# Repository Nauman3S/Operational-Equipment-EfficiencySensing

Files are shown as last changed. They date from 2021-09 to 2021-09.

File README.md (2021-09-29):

<p align="center">
  <a href="" rel="noopener">
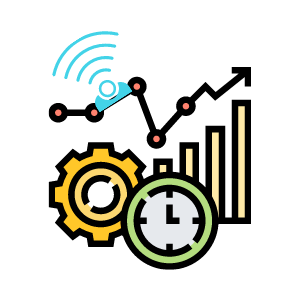
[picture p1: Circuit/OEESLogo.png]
Project logo
 </a>
</p>

<h3 align="center">Operational Equipment Efficieny Sensing</h3>

<div align="center">

[]()

</div>

---

<p align="center"> Operational Equipment Efficieny Sensing
    <br> 
</p>

## 📝 Table of Contents

- [About](#about)
- [Getting Started](#getting_started)
- [RPiClient Installation](#Installation)
- [Circuit](#circuit)
- [Usage](#usage)
- [Built Using](#built_using)
- [Authors](#authors)

## 🧐 About 

This repo contains

- Firmware
- Circuit Diagram
- Detailed instructions

for OEESensing project.

## Getting Started 

These instructions will get you a copy of the project up and running on your system.

### Prerequisites

Things you need to install the FW.

```
- Arduino IDE
```

### Installing 

A step by step series that tell you how to get the Firmware and Backend running

#### ESP32 Configuration

You should have Arduino IDE Installed

  1.  Add ESP32 Board to your Arduino IDE
    1. In your Arduino IDE, go to File> Preferences
        Installing ESP32 Add-on in Arduino IDE Windows, Mac OS X, Linux open preferences
    2. Enter ```https://dl.espressif.com/dl/package_esp32_index.json``` 
        into the “Additional Board Manager URLs” field then, click the “OK” button:
        Note: if you already have the ESP32 boards URL, you can separate the URLs with a comma(each board will go to neaw line) as follows:
        ```https://dl.espressif.com/dl/package_esp32_index.json,\n http://arduino.esp8266.com/stable/package_esp8266com_index.json```

  2. Open the Boards Manager. Go to Tools > Board > Boards Manager…
  3. Search for ESP32 and press install button for the ESP32 by Espressif Systems“:
  4. That’s it. It should be installed after a few seconds.
  5.   In your Arduino sketchbook directory, create tools directory if it doesn't exist yet.
  6.  Unpack the tool into tools directory(present in libs/ESP32FS-1.0.zip) (the path will look like <home_dir>/Arduino/tools/ESP32FS/tool/esp32fs.jar).
  7.  Close and re-open the Arduino IDE.

  8.  Now copy the contents of the libs folder to the libraries directory of your Arduino
      1. If you are using windows, the libraries directory will be Documents/Arduino/libraries

##### ESP32 Node FW Uploading
  1.  Select ESP32 Dev Module from Tools->Board->ESP32
  2.  Select the correct port from Tools->Port
  3.  Then open Firmware.ino file,
  4.  Select Tools > ESP32 Sketch Data Upload menu item. This should start uploading the files into ESP32 flash file system.
  5.  Now Upload the Code to your ESP32 Dev Module.
  6.  Your ESP32 is now ready to be used.

## Circuit 

### ESP32 Dev Module Pinout

Follow the pinout diagram given below to connect different components to your TTGO LORA32 board.

![LoraPinout](Circuit/ESP32-Pinout.jpg)

### Other Components

```http
Other components pin connection details
```

#### Temperature Sensor DHT22

```DHT22 Connections```

| DHT22 Pins | ESP32 Dev Module Pins| 
| :--- | :--- | 
| `DATA OUT` | `23` |
| `VCC` | `5V` |
| `GND` | `GND` | 

#### Vibration Sensor(MPU6050)

```MPU6050 Connections```

| MPU6050 Pins | ESP32 Dev Module | 
| :--- | :--- | 
| `SCL` | `22` |
| `SDA` | `21` |
| `VCC` | `3.3V` |
| `GND` | `GND` | 

#### Status LED

```LED Connections```

| LED Pins | ESP32 Dev Module | 
| :--- | :--- | 
| `Anode` | `D2 via 220Ω resistor` |
| `Cathode` | `GND` |
*D2 is also connected to the internal LED of ESP32 Dev Module*

#### SCT-013 

```SCT-013 Connections```

-   Voltage Divider with 2x 100KΩ resistors.
-   10uF capacitor connected between Voltage Divider Circuit Output and GND
-   3.5mm Audio Jack connected between Voltage Divider Circuit Output and ESP32 Pin 34.

The overall SCT-013 connection assembly will look something like shown in the diagram below.

![SCTConnection](Circuit/sctWiring.jpg)

### Complete Circuit Diagram

Here's the complete circuit diagram of the system.

![CircuitDiagram](Circuit/Circuit_bb.png)

## Usage 

1.  Power on your ESP32, it will present you with an AP named ```OEE``` (while ```OEE``` can be changed in the portal)
2.  Default captive portal password `12345678AP` which can be changed in captive portal.
3.  Connect to the ESP32 access point and open the web-browser and navigate to the link ```http://esp32.local/_ac```. This link will work on most of the operating systems but if your operating system is not allowing to open it, you may want to check the captive portal IP Address from the serial monitor and can use that IP address inplace of the above mentioned URL.
4.  The default access IP Address is ```http://192.168.4.1/_ac```
5.  You will be presented with a main dashboard as shown below(based on your device)
   ![SCR1](Circuit/scr1.png)

5.  Once connected to a WiFi network, you can again access the captive portal using same URL or the IP Address from the Serial monitor.
6.  The data is published to the MQTT Topic ```OEE/{hostname}``` while the hostname is the one which you can define in Settings page of the captive portal.

The whole system is following the flowchart given below:

   ![flow](Circuit/flow.png)

### Changing Timezone

1.  Open Settings tab
2.  Enter timezone string from https://en.wikipedia.org/wiki/List_of_tz_database_time_zones 'TZ database name' column.
3.  Click Save&Start

### API Endpoints and HTML URLS
```API Endpoints```

| Endpoint | Description | 
| :--- | :--- | 
| `/api-now` | `API: live sensor readings in JSON format` |
| `/api` | `API: historical sensors data in JSON format` |
| `/LiveSensors` | `HTML PAGE: Live Sensor Data` |
| `/data` | `HTML PAGE: Historical Sensor Data` | 
| `/mqtt_settings` | `HTML PAGE: Settings. Default username: AP Name, Default Password: admin` | 
| `/_ac` | `HTML PAGE: Main Captive portal page` | 
| `/` | `HTML PAGE: Historical Sensor Data` | 

1.  **Connect to WiFi** tab allows searching of nearby WiFi APs and adding them to the ESP32.
   ![SCR3](Circuit/scr3.png)
7.  **Saved WiFi Networks** tab allows connecting to the saved access points.
   ![SCR4](Circuit/scr4.png)
8.  **Reset...** tab allows reseting of the device to factory settings.
    ![SCR5](Circuit/scr5.png)
9.  **Settings** tab contains settings related to MQTT and sensors.
    ![SCR6](Circuit/scr6.png)
10. **api-now** tab gives the live-sensor data in JSON format.
    ![SCR7](Circuit/scr7.png)
11. **api** tab gives the historical sensor data acquired after every 5 mintues.
    ![SCR9](Circuit/scr9.png)
13. **LiveSensors** tab shows live values of the sensors.
    ![SCR8](Circuit/scr8.png)
12. **HOME** tab shows historical sensor data in a HTML table form acquired after every 5 minutes.
    ![SCR10](Circuit/scr10.png)

## List of Components 

Following components are used to make this project

1.  ESP32 Dev Kit Module
https://www.amazon.com/HiLetgo-ESP-WROOM-32-Development-Microcontroller-Integrated/dp/B0718T232Z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

2.  Current Sensor (SCT-013)
https://www.amazon.com/dp/B083S6YG36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

3.  DHT22 Temperature and Humidity Sensor
https://www.amazon.com/Gowoops-Temperature-Humidity-Measurement-Raspberry/dp/B073F472JL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

4.  Vibration Sensor (IMU) (MPU6050)
https://www.amazon.com/HiLetgo-MPU-6050-Accelerometer-Gyroscope-Converter/dp/B00LP25V1A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

5.  Generic 3.5mm Green LED
6.  Generic 3.5mm Audio Jack
7.  Generic 10uF 25v Capacitor
8.  Generic 220Ω and 100KΩ resistors
9.  Generic 5V USB Micro B cable and adapter.

## ⛏️ Built Using 

- [Python](https://www.python.org/) - For Cloud Gateway Pogramming
- [Arduino](https://www.arduino.cc/) - Embedded Framework and IDE - For Sensor Node Design

## 📹 Demo Videos 

-   [Device Demo Video](https://youtu.be/YtVo1j4n8tg) - OEE Device Demo Video

## ✍️ Authors 

- [@Nauman3S](https://github.com/Nauman3S) - Development and Deployment

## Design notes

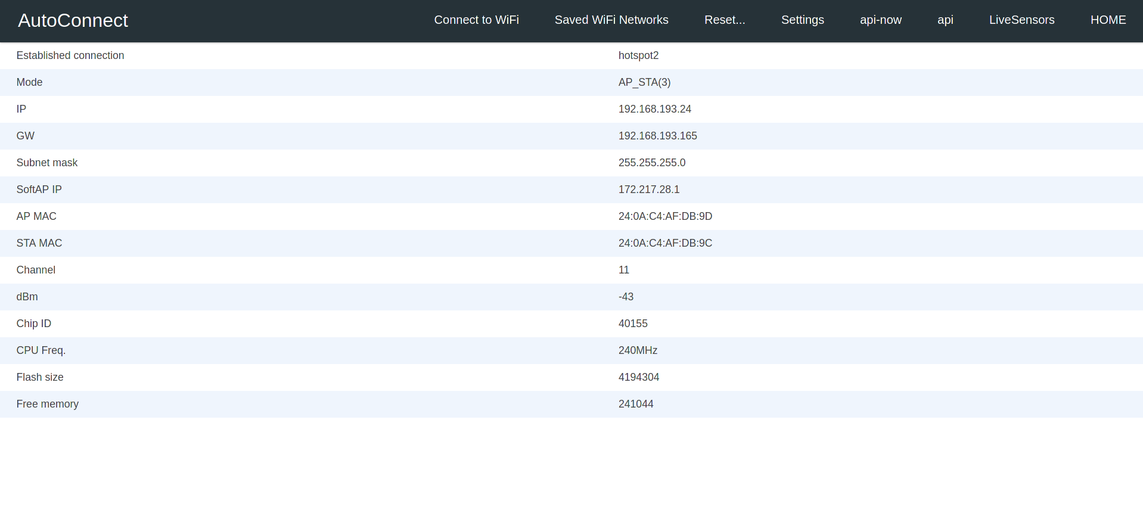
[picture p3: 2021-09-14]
Circuit/scr1.png

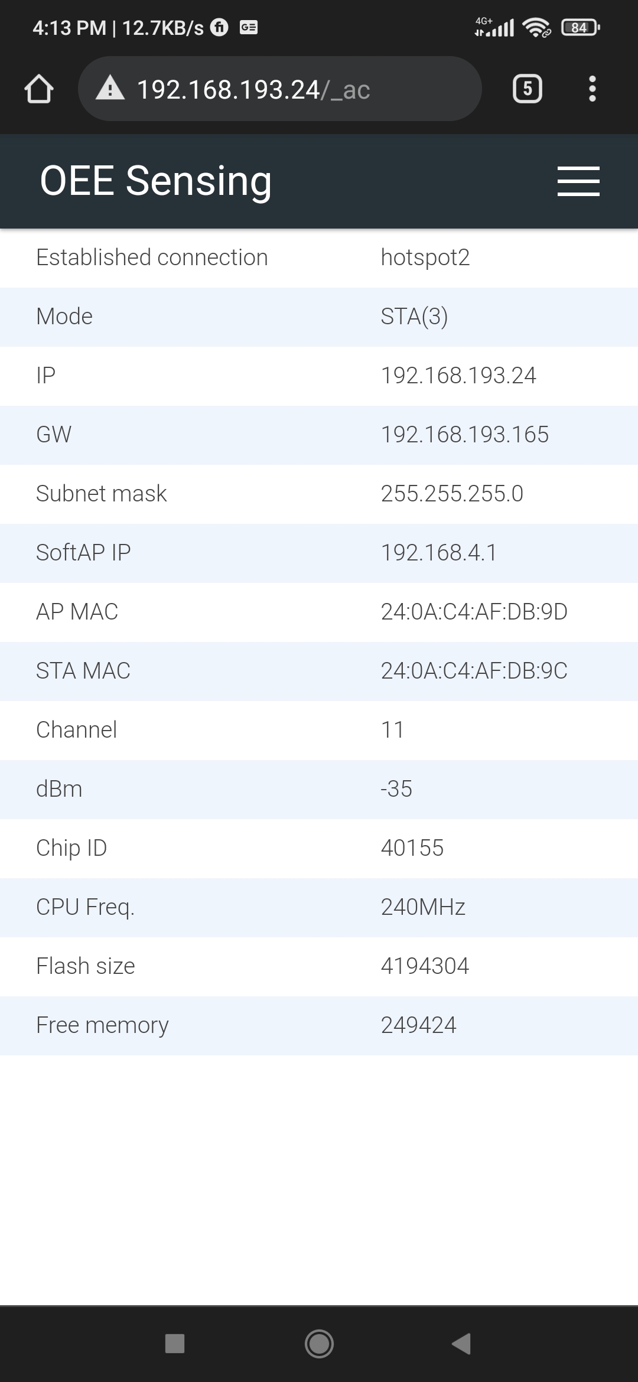
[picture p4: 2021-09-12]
Circuit/scr2.jpg

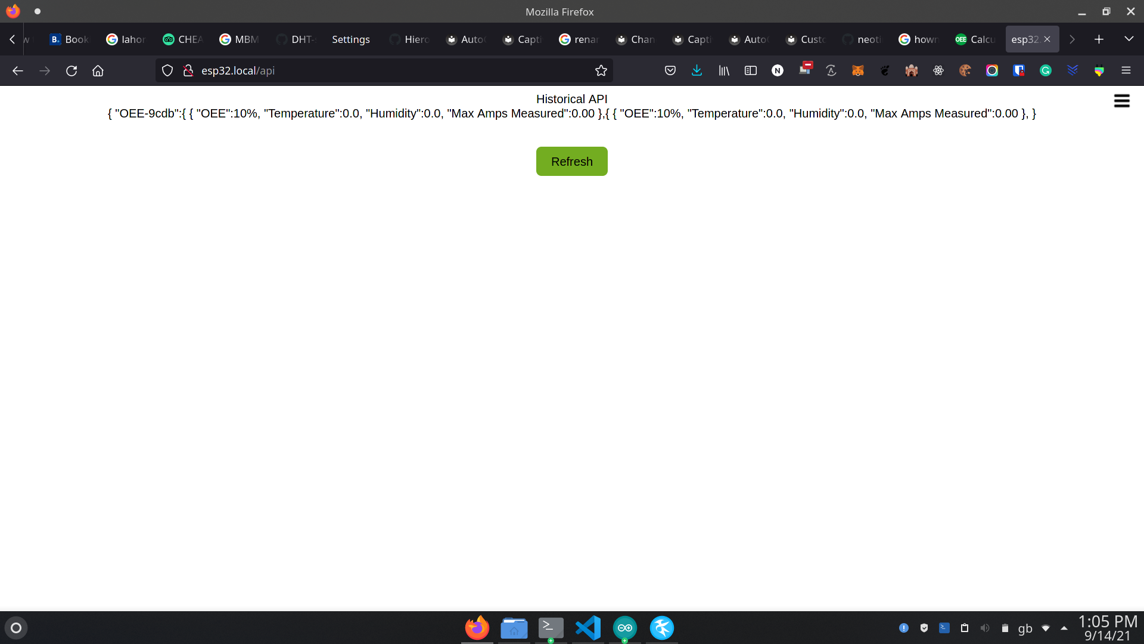
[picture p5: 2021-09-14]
Circuit/scr9.png

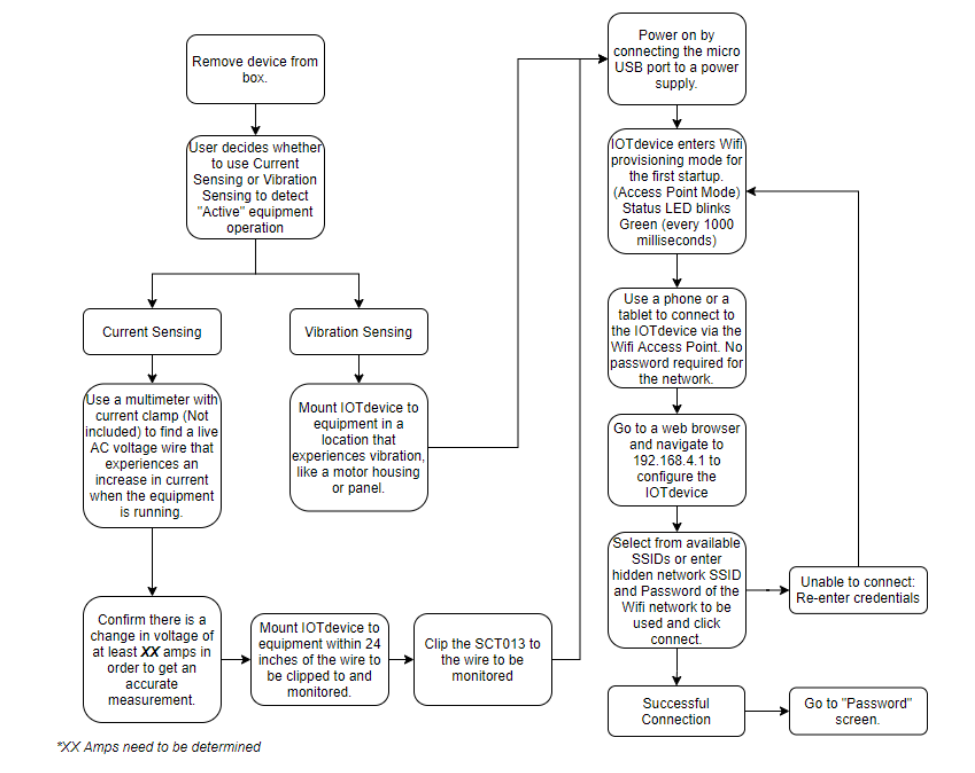
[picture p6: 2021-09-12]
Circuit/flow.png

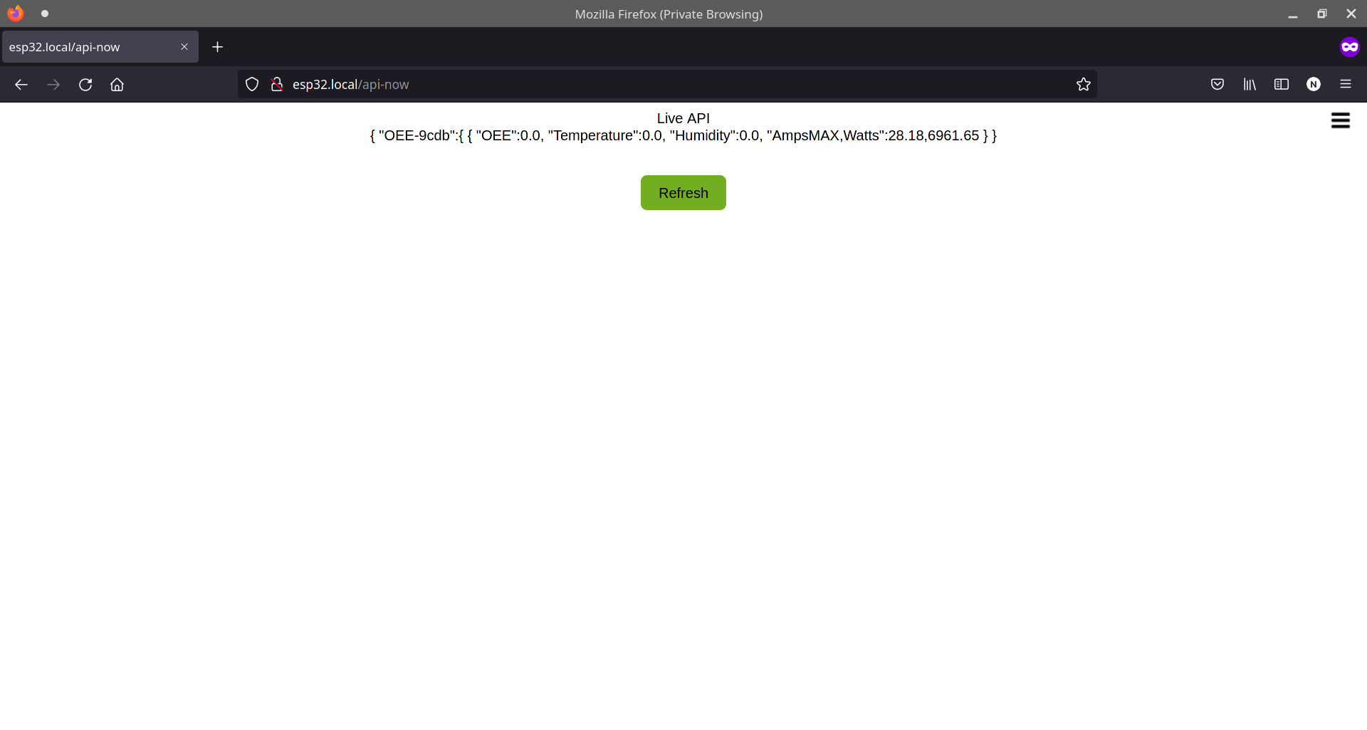
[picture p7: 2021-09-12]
Circuit/scr7.png

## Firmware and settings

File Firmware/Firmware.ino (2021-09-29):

#include "dhtHandler.h"           //temperature and humidity functions
#include "mpu6050Handler.h"       //IMU MPU6050 functions
#include "currentSesnorHandler.h" //current sensor functions
#include "headers.h"              //all misc. headers and functions
#include "esp32InternalTime.h"
#include "MQTTFuncs.h" //MQTT related functions
#include "webApp.h"    //Captive Portal webpages
#include <FS.h>        //ESP32 File System

const long interval = 1000 * 60 * 5;        // Interval at which to read sensors//5 mintues
Neotimer dataAcqTimer = Neotimer(interval); // Set timer's preset
Neotimer sensorsDataTimer = Neotimer(1000); // Set timer's preset

IPAddress ipV(192, 168, 4, 1);
String loadParams(AutoConnectAux &aux, PageArgument &args) //function to load saved settings
{
    (void)(args);
    File param = FlashFS.open(PARAM_FILE, "r");
    String v1 = "";
    String v2 = "";
    if (param)
    {
        Serial.println("load params func");
        aux.loadElement(param);
        Serial.println(param);
        //Serial.println(args);
        AutoConnectText &vibSValueElm = aux["vibSValue"].as<AutoConnectText>();
        AutoConnectText &curSValueElm = aux["curSValue"].as<AutoConnectText>();
        //vibSValueElm.value="VibS:91122";#
        Serial.println(vibSValueElm.value);
        v1 = String(vibSValueElm.value);
        v2 = String(curSValueElm.value);
        if (v1.length() > 0)
        {
            vibSValueElm.value = String("Vibration: ") + getMPU6050Data();
        }
        if (v2.length() > 0)
        {
            curSValueElm.value = String("Current: ") + getCurrentWatts();
        }
        // curSValueElm.value="CurS:7788";
        param.close();
    }
    else
        Serial.println(PARAM_FILE " open failed");
    return String("");
}

String saveParams(AutoConnectAux &aux, PageArgument &args) //save the settings
{
    serverName = args.arg("mqttserver"); //broker
    serverName.trim();

    channelId = args.arg("channelid");
    channelId.trim();

    userKey = args.arg("userkey"); //user name
    userKey.trim();

    apiKey = args.arg("apikey"); //password
    apiKey.trim();

    timezone = args.arg("timezone"); //timezone
    timezone.trim();

    minActiveValue = args.arg("minActiveValue");
    minActiveValue.trim();

    ampSensorType = args.arg("ampSensorType");
    ampSensorType.trim();
    ampSensorType = ampSensorType.substring(0, 2);

    tempUnits = args.arg("tempUnits");
    tempUnits.trim();

    String upd = args.arg("period");
    upd = upd.substring(0, 2);
    sensorSelection = upd;

    apPass = args.arg("apPass"); //ap pass
    apPass.trim();

    settingsPass = args.arg("settingsPass"); //ap pass
    settingsPass.trim();

    hostName = args.arg("hostname");
    hostName.trim();

    // The entered value is owned by AutoConnectAux of /mqtt_setting.
    // To retrieve the elements of /mqtt_setting, it is necessary to get
    // the AutoConnectAux object of /mqtt_setting.
    File param = FlashFS.open(PARAM_FILE, "w");
    portal.aux("/mqtt_setting")->saveElement(param, {"mqttserver", "channelid", "userkey", "apikey", "timezone", "period", "minActiveValue", "ampSensorType", "tempUnits", "hostname", "apPass", "settingsPass"});
    param.close();

    // Echo back saved parameters to AutoConnectAux page.
    AutoConnectText &echo = aux["parameters"].as<AutoConnectText>();
    echo.value = "Server: " + serverName + "<br>";
    echo.value += "Channel ID: " + channelId + "<br>";
    echo.value += "Timezone: " + timezone + "<br>";
    echo.value += "Username: " + userKey + "<br>";
    echo.value += "Password: " + apiKey + "<br>";
    echo.value += "Sensor Settings: " + String(upd) + "<br>";
    echo.value += "Min Active Value: " + minActiveValue + "<br>";
    echo.value += "Amp Sensor Type: " + ampSensorType + "<br>";
    echo.value += "Temperature Units: " + tempUnits + "<br>";
    echo.value += "ESP host name: " + hostName + "<br>";
    echo.value += "AP Password: " + apPass + "<br>";
    echo.value += "Settings Page Password: " + settingsPass + "<br>";
    mqttPublish("OEEDevice/dev/config", String("tz;") + timezone); //publish timezone info
    return String("");
}
bool loadAux(const String auxName) //load defaults from data/*.json
{
    bool rc = false;
    Serial.println("load aux func");
    String fn = auxName + ".json";
    File fs = FlashFS.open(fn.c_str(), "r");
    if (fs)
    {
        rc = portal.load(fs);
        fs.close();
    }
    else
        Serial.println("Filesystem open failed: " + fn);
    return rc;
}
uint8_t inAP = 0;
bool whileCP()
{

    if (inAP == 0)
    {
        ledState(AP_MODE);
        inAP = 1;
    }
    // Serial.println("AP MODE");

    loopLEDHandler();
}

void setup() //main setup functions
{
    Serial.begin(115200);
    delay(1000);
    setupDHT22();
    setupMPU6050();
    setupCurrentSensor();

    if (!MDNS.begin("esp32")) //starting mdns so that user can access webpage using url `esp32.local`(will not work on all devices)
    {
        Serial.println("Error setting up MDNS responder!");
        while (1)
        {
            delay(1000);
        }
    }
#if defined(ARDUINO_ARCH_ESP8266)
    FlashFS.begin();
#elif defined(ARDUINO_ARCH_ESP32)
    FlashFS.begin(true);
#endif
    loadAux(AUX_MQTTSETTING);
    loadAux(AUX_MQTTSAVE);
    AutoConnectAux *setting = portal.aux(AUX_MQTTSETTING);
    if (setting) //get all the settings parameters from setting page on esp32 boot
    {
        Serial.println("Setting loaded");
        PageArgument args;
        AutoConnectAux &mqtt_setting = *setting;
        loadParams(mqtt_setting, args);
        AutoConnectInput &hostnameElm = mqtt_setting["hostname"].as<AutoConnectInput>();
        AutoConnectInput &apPassElm = mqtt_setting["apPass"].as<AutoConnectInput>();
        AutoConnectInput &serverNameElm = mqtt_setting["mqttserver"].as<AutoConnectInput>();
        AutoConnectInput &channelidElm = mqtt_setting["channelid"].as<AutoConnectInput>();
        AutoConnectInput &userkeyElm = mqtt_setting["userkey"].as<AutoConnectInput>();
        AutoConnectInput &apikeyElm = mqtt_setting["apikey"].as<AutoConnectInput>();
        AutoConnectInput &minActiveValueElm = mqtt_setting["minActiveValue"].as<AutoConnectInput>();
        AutoConnectRadio &ampSensorTypeElm = mqtt_setting["ampSensorType"].as<AutoConnectRadio>();
        AutoConnectRadio &tempUnitsElm = mqtt_setting["tempUnits"].as<AutoConnectRadio>();
        AutoConnectRadio &periodElm = mqtt_setting["period"].as<AutoConnectRadio>();
        AutoConnectText &vibSValueElm = mqtt_setting["vibSValue"].as<AutoConnectText>();
        AutoConnectText &curSValueElm = mqtt_setting["curSValue"].as<AutoConnectText>();
        AutoConnectInput &settingsPassElm = mqtt_setting["settingsPass"].as<AutoConnectInput>();
        //vibSValueElm.value="VibS:11";
        serverName = String(serverNameElm.value);
        channelId = String(channelidElm.value);
        userKey = String(userkeyElm.value);
        apiKey = String(apikeyElm.value);
        minActiveValue = String(minActiveValueElm.value);
        ampSensorType = String(ampSensorTypeElm.value());
        tempUnits = String(tempUnitsElm.value());
        sensorSelection = String(periodElm.value());
        hostName = String(hostnameElm.value);
        apPass = String(apPassElm.value);
        settingsPass = String(settingsPassElm.value);
        if (hostnameElm.value.length())
        {
            //hostName=hostName+ String("-") + String(GET_CHIPID(), HEX);
            //;
            //portal.config(hostName.c_str(), apPass.c_str());
            // portal.config(hostName.c_str(), "123456789AP");
            config.apid = hostName; //hostnameElm.value+ "-" + String(GET_CHIPID(), HEX);
            config.password = apPass;
            config.psk = apPass;
            // portal.config(hostName.c_str(), "123456789AP");
            Serial.println("(from hostELM) hostname set to " + hostName);
        }
        else
        {

            // hostName = String("OEE");;
            // portal.config(hostName.c_str(), "123456789AP");
            config.apid = hostName; //hostnameElm.value+ "-" + String(GET_CHIPID(), HEX);
            config.password = apPass;
            config.psk = apPass;
            //config.hostName = hostName;//hostnameElm.value+ "-" + String(GET_CHIPID(), HEX);
            // portal.config(hostName.c_str(), "123456789AP");
            Serial.println("hostname set to " + hostName);
        }
        config.homeUri = "/_ac";
        config.apip = ipV;

        portal.on(AUX_MQTTSETTING, loadParams);
        portal.on(AUX_MQTTSAVE, saveParams);
    }
    else
    {
        Serial.println("aux. load error");
    }
    //config.homeUri = "/_ac";
    config.apip = ipV;
    config.autoReconnect = true;
    config.reconnectInterval = 1;
    Serial.print("AP: ");
    Serial.println(hostName);
    Serial.print("Password: ");
    Serial.println(apPass);
    config.title = "OEE Sensing"; //set title of webapp

    //add different tabs on homepage
    portal.append("/api-now", "api-now");
    portal.append("/api", "api");
    portal.append("/LiveSensors", "LiveSensors");
    portal.append("/data", "DataTable");
    portal.disableMenu(AC_MENUITEM_DISCONNECT);
    server.on("/", handleRoot);
    server.on("/api-now", cmotsValues);
    server.on("/api", api);
    server.on("/LiveSensors", live);
    server.on("/data", dataTable);
    // Starts user web site included the AutoConnect portal.

    config.auth = AC_AUTH_DIGEST;
    config.authScope = AC_AUTHSCOPE_PARTIAL;
    config.username = hostName;
    config.password = settingsPass;

    portal.config(config);
    portal.whileCaptivePortal(whileCP);
    portal.onDetect(atDetect);
    portal.load(FPSTR(PAGE_AUTH));
    if (portal.begin())
    {
        Serial.println("Started, IP:" + WiFi.localIP().toString());
        ledState(AP_MODE);
    }
    else
    {
        Serial.println("Connection failed.");
        while (true)
        {
            yield();
            delay(100);
        }
    }

    MDNS.addService("http", "tcp", 80);
    mqttConnect(); //start mqtt
}

void loop()
{
    server.handleClient();
    portal.handleRequest();
    loopLEDHandler();
    if (dataAcqTimer.repeat())
    {
        ss.calculateOEEValue();

        OEEValue = ss.getOEEValue();
        ss.addSensorValue(getTimestamp(), OEEValue, getTemp(tempUnits), getHumid(), getCurrentWatts());
    }
    if (sensorsDataTimer.repeat())
    {
        getMPU6050Data();
        ss.acquireAndStoreCurrentSensorValues_OEE(getCurrentWatts());
    }
    if (millis() - lastPub > updateInterval) //publish data to mqtt server
    {
        mqttPublish("OEE/" + String(hostName), getTimestamp() + String(";") + getTempHumid(tempUnits) + String(";") + getMPU6050Data() + String(";") + getCurrentWatts()); //publish data to mqtt broker
        ledState(ACTIVE_MODE);
        //uncomment the lines below for debugging
        // Serial.println(ampSensorType);
        // Serial.println(sensorSelection);
        // Serial.println(minActiveValue);
        // Serial.println(channelId);
        // Serial.println(userKey);
        // Serial.println(apiKey);
        // Serial.println(apid);
        // Serial.println(hostName);
        // Serial.println(apPass);
        // Serial.println(tempUnits)

        lastPub = millis();
    }
    if (!mqttClient.connected())
    {
        reconnect();
    }
    mqttClient.loop();
    if (WiFi.status() == WL_IDLE_STATUS)
    {
        ledState(IDLE_MODE);
        ESP.restart();

        delay(1000);
    }
}

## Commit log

2021-09-12 updated readme, added circuit
    [Circuit.fzz]
2021-09-13 updated readme, circuit diagram
    [Circuit.fzz]
2021-09-14 added temperature units and logic to fw
2021-09-14 updated readme and circuit diagram
    [Circuit.fzz]
2021-09-18 updated fw for correct OEE calculations
    [Firmware.ino]
2021-09-25 led corrected
2021-09-25 updated led pin for azure kit
2021-09-29 updated vibration formula to get two readings 1000ms apart and sum the difference of all values
    [Firmware.ino]
